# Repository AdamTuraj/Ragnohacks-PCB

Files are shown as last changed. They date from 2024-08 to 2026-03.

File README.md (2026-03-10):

# Ragnohacks PCB

This is the repo containing the design files for the PCB which may be used in the [Ragnohacks hackathon](https://ragnohacks.ca)

## 3D PCB Preview
Top preview
Bottom preview

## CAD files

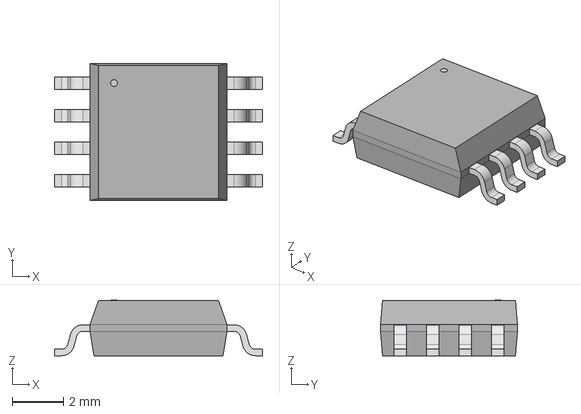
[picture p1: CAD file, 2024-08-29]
STEP/SOIC_128JVSIQ_WIN.step
8.10 x 5.33 x 2.16 mm

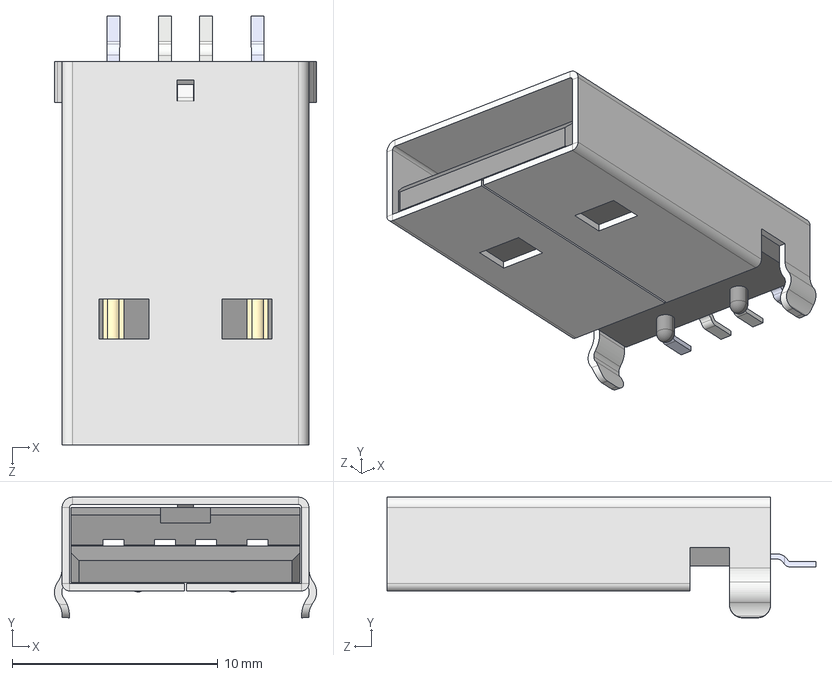
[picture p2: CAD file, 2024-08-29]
STEP/USB_A.STEP
12.7 x 5.86 x 20.8 mm

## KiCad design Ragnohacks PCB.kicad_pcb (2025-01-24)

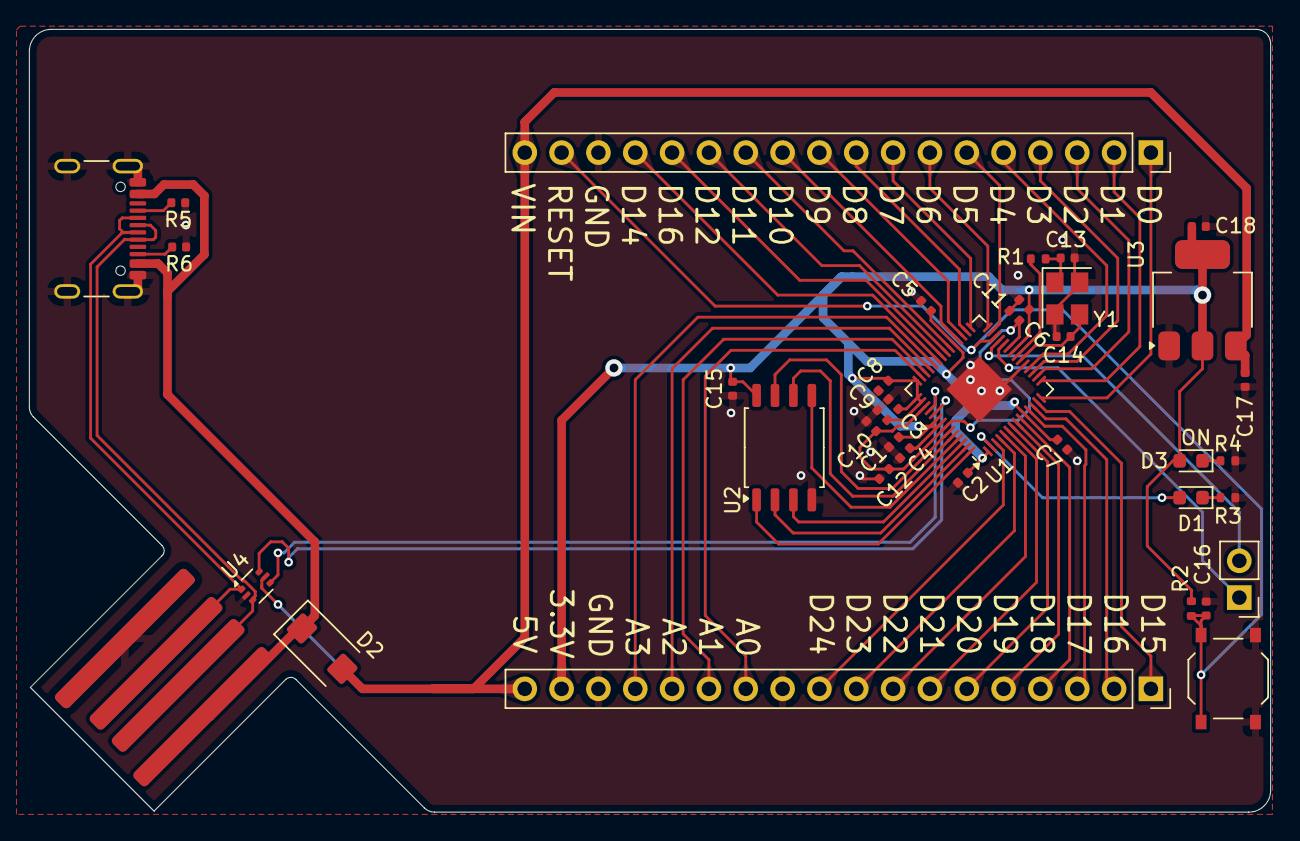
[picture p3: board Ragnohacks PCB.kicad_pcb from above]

Board: 2 copper layers, 85.6 x 54.0 mm, 38 parts (0 on the bottom side), 55 nets.

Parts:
C1, C2, C3, C4, C5, C6, C7, C8, C11, C12, C15, C16, C17: 0.1uF; C_0402_1005Metric
C9, C10: 1uF; C_0402_1005Metric
C13, C14: 18pF; C_0402_1005Metric
C18: 10uF; C_0402_1005Metric
D1, D3: LED; LED_0603_1608Metric
D2: D_Schottky; D_SMA
J1: Conn_01x02; PinHeader_1x02_P2.54mm_Vertical
J2, J3: Conn_01x18; PinSocket_1x18_P2.54mm_Vertical
J4: USB_A; USB_A_Edge
J5: USB_C_Receptacle_USB2.0_16P; USB_C_Receptacle_GCT_USB4105-xx-A_16P_TopMnt_Horizontal
R1: 1k; R_0402_1005Metric
R2: 10k; R_0402_1005Metric
R3, R4: 360R; R_0402_1005Metric
R5, R6: 5k1; C_0402_1005Metric
SW1: SW_Push; SW_Push_1P1T_XKB_TS-1187A
U1: RP2040; QFN-56-1EP_7x7mm_P0.4mm_EP3.2x3.2mm
U2: W25Q128JVS; SOIC-8_5.23x5.23mm_P1.27mm
U3: LD1117S33TR_SOT223; SOT-223-3_TabPin2
U4: USBLC6-2P6; SOT-666
Y1: 12MHz; Crystal_SMD_3225-4Pin_3.2x2.5mm

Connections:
+1V1: C10.1, C11.1, C12.1, U1.23 (DVDD), U1.45 (VREG_VOUT), U1.50 (DVDD)
+3V3: C1.1, C2.1, C3.1, C4.1, C5.1, C6.1, C7.1, C8.1, C9.1, C15.1, C18.1, D3.2 (A), J3.17, R2.2, U1.1 (IOVDD), U1.10 (IOVDD), U1.22 (IOVDD), U1.33 (IOVDD), U1.42 (IOVDD), U1.43 (ADC_AVDD), U1.44 (VREG_IN), U1.48 (USB_VDD), U1.49 (IOVDD), U2.8 (VCC), U3.2 (VO)
+5V: C17.1, D2.1 (K), J2.18, J3.18, U3.3 (VI), U4.5 (VBUS)
A0: J3.12, U1.41 (GPIO29_ADC3)
A1: J3.13, U1.40 (GPIO28_ADC2)
A2: J3.14, U1.39 (GPIO27_ADC1)
A3: J3.15, U1.38 (GPIO26_ADC0)
D0: J2.1, U1.14 (GPIO11)
D1: J2.2, U1.15 (GPIO12)
D2: J2.3, U1.16 (GPIO13)
D3: J2.4, U1.17 (GPIO14)
D4: J2.5, U1.18 (GPIO15)
D5: J2.6, U1.27 (GPIO16)
D6: J2.7, U1.28 (GPIO17)
D7: J2.8, U1.29 (GPIO18)
D8: J2.9, U1.30 (GPIO19)
D9: J2.10, U1.31 (GPIO20)
D10: J2.11, U1.32 (GPIO21)
D11: J2.12, U1.34 (GPIO22)
D12: J2.13, U1.35 (GPIO23)
D13: J2.14, U1.36 (GPIO24)
D14: J2.15, U1.37 (GPIO25)
D15: J3.1, U1.13 (GPIO10)
D16: J3.2, U1.12 (GPIO9)
D17: J3.3, U1.11 (GPIO8)
D18: J3.4, U1.9 (GPIO7)
D19: J3.5, U1.8 (GPIO6)
D20: J3.6, U1.7 (GPIO5)
D21: J3.7, U1.6 (GPIO4)
D22: J3.8, U1.5 (GPIO3)
D23: J3.9, U1.4 (GPIO2)
D24: J3.10, U1.3 (GPIO1)
DN: J4.3 (D+), J5.A7 (D-), J5.B7 (D-), U4.1 (I/O1)
DP: J4.2 (D-), J5.A6 (D+), J5.B6 (D+), U4.3 (I/O2)
FLASH_CLK: U1.52 (QSPI_SCLK), U2.6 (CLK)
FLASH_CS: U1.56 (QSPI_SS), U2.1 (~CS)
FLASH_SD0: U1.53 (QSPI_SD0), U2.5 (DI(IO0))
FLASH_SD1: U1.55 (QSPI_SD1), U2.2 (DO(IO1))
FLASH_SD2: U1.54 (QSPI_SD2), U2.3 (IO2)
FLASH_SD3: U1.51 (QSPI_SD3), U2.7 (IO3)
GND: C1.2, C2.2, C3.2, C4.2, C5.2, C6.2, C7.2, C8.2, C9.2, C10.2, C11.2, C12.2, C13.1, C14.1, C15.2, C16.1, C17.2, C18.2, J2.16, J3.11, J3.16, J4.4 (GND), J4.5 (Shield), J5.A1 (GND), J5.A12 (GND), J5.B1 (GND), J5.B12 (GND), J5.S1 (SHIELD), R3.2, R4.2, R5.1, R6.1, SW1.1, U1.19 (TESTEN), U1.57 (GND), U2.4 (GND), U3.1 (GND), U4.2 (GND), Y1.2, Y1.4
LED_25: D1.2 (A), U1.2 (GPIO0)
unnamed: C13.2, R1.1, Y1.1
unnamed: D1.1 (K), R3.1
unnamed: D2.2 (A), J4.1 (VBUS), J5.A4 (VBUS), J5.A9 (VBUS), J5.B4 (VBUS), J5.B9 (VBUS)
unnamed: D3.1 (K), R4.1
unnamed: J1.1, U1.24 (SWCLK)
unnamed: J1.2, U1.25 (SWD)
unnamed: J5.A5 (CC1), R5.2
unnamed: J5.B5 (CC2), R6.2
unnamed: C14.2, U1.20 (XIN), Y1.3
unnamed: R1.2, U1.21 (XOUT)
RESET: C16.2, J2.17, R2.1, SW1.2, U1.26 (RUN)
USB_DN: U1.46 (USB_DM), U4.4 (I/O2)
USB_DP: U1.47 (USB_DP), U4.6 (I/O1)

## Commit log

2024-08-29 Finish schematic
    [Ragnohacks PCB.kicad_pcb, Ragnohacks PCB.kicad_sch]
2024-08-29 Finish schematic and part choosing, get initial quote
    [Ragnohacks PCB.kicad_pcb, Ragnohacks PCB.kicad_sch]
2024-08-29 Start layout, add PCBWay parts
    [Ragnohacks PCB.kicad_pcb, Ragnohacks PCB.kicad_sch]
2024-08-29 Start tracing
    [Ragnohacks PCB.kicad_pcb]
2024-08-29 Finish tracing pins
    [Ragnohacks PCB.kicad_pcb]
2024-08-29 Finish tracing
    [Ragnohacks PCB.kicad_pcb, Ragnohacks PCB.kicad_sch]
2024-08-29 The finishing touches
    [Ragnohacks PCB.kicad_pcb, Ragnohacks PCB.kicad_sch, SOIC_128JVSIQ_WIN.step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]
2024-08-31 Change USB port, adjust header position, start tracing
    [Ragnohacks PCB.kicad_pcb, Ragnohacks PCB.kicad_sch]
2024-09-02 Rev 2 of the Ragnohacks PCB
    [Ragnohacks PCB.kicad_pcb, Ragnohacks PCB.kicad_sch]
2024-09-02 Move USB port, routing adjustments
    [Ragnohacks PCB.kicad_pcb]
2025-01-24 Swap USB pins
    [Ragnohacks PCB.kicad_pcb, Ragnohacks PCB.kicad_sch]
2026-03-10 Replace PCB preview images with updated links
    Updated image links for 3D PCB previews in README.
